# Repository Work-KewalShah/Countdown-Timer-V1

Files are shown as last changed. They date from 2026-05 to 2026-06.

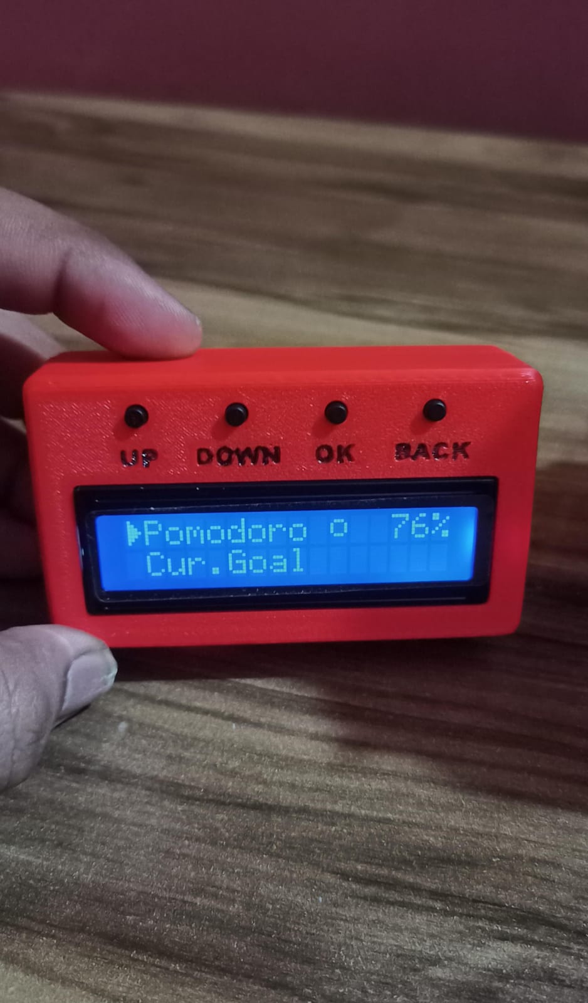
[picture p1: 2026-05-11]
images/Countdown_Timer_Build_Front.jpeg

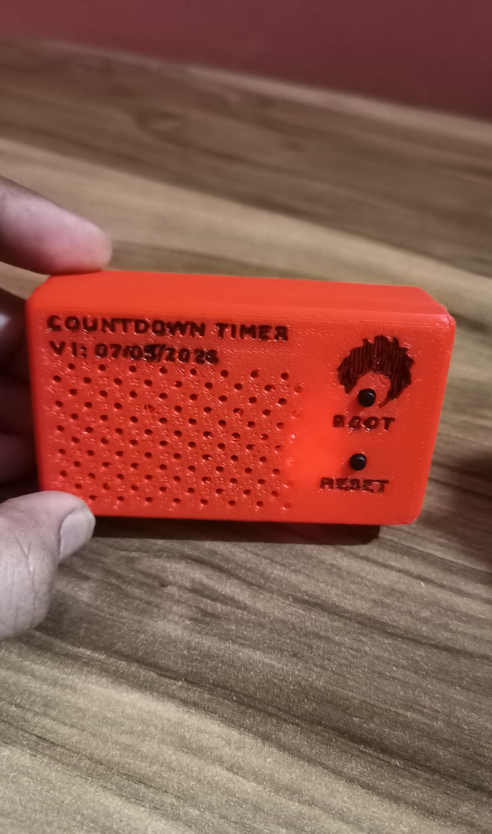
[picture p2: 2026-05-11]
images/Countdown_Timer_Build_Back.jpeg

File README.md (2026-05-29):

# Countdown Timer V1

<div align="center">
  Countdown Timer Hero Shot
</div>

<br/>

<div align="center">
  A battery-powered handheld countdown timer built on ESP32 with a 3D printed snap-fit case - track multiple goals simultaneously, run a stopwatch, save state across power cycles, and play a cute little game while you wait.
</div>

---

## Badges

<div align="center">







</div>

---

## Gallery

<div align="center">

| | |
|:---:|:---:|
| Countdown Timer - Build Front | Countdown Timer - Build Back |
| Build - Front | Build - Back |
| Countdown Timer - Front | Countdown Timer - Back |
| Render - Front | Render - Back |

</div>

---

## Table of Contents

- [What Is This](#what-is-this)
- [Features](#features)
- [Hardware](#hardware)
- [Wiring](#wiring)
- [How It Works - Software](#how-it-works---software)
- [Case Design](#case-design)
- [Programming the Device](#programming-the-device)
- [Skills Learned](#skills-learned)
- [Major Problems and Solutions](#major-problems-and-solutions)
- [V2 Planned Improvements](#v2-planned-improvements)
- [Repository Structure](#repository-structure)
- [License](#license)
- [Author](#author)

---

> This project exists because I needed to learn 3D Modelling and the only way I prefer learning something is by building something real with it, not by simply following tutorials.
>
> One week. Zero prior CAD experience. A functional snap-fit enclosure with port cutouts, engraved logos, ventilation geometry, toleranced joints, and a deadline I set for myself.
>
> The timer on the device was literally counting down to its own completion ;)

---

## What Is This

I generally build dedicated hardware devices for my own use - tools that solve specific problems in how I work and think. This is one of them.

I was deep into building a handheld Cyberdeck - most of the electronics and software were done, but the case design remained. I had never done 3D modelling before and needed to learn it properly with accurate dimensions, custom fits, and proper strain free joints. I needed a smaller, simpler project to learn on before tackling the Cyberdeck case with complex fixtures and fittings.

The project idea came one night when I was thinking about the Cyberdeck itself. I had set a deadline to finish it but the deadline kept slipping - I was only at 60% completion and had been for a while. The problem was not motivation, it was visibility. If I cannot physically see a deadline, I tend to procrastinate or keep adding scope without realising how much is already on my plate. That is true for the Cyberdeck (I kept adding features after features on top of an already stacked lineup) and for most of my tasks.

So the idea was simple - build a physical device that shows me exactly how much time is left for my current goal. Not a phone app. Not a widget on a screen I share with twenty other distractions. A dedicated physical object sitting on my desk with one job: show me the time I have left!

I also tend to prefer staying disconnected from my phone for most of my work - I use it for calls and messages, which is what phones were originally for. Separate dedicated devices for music, timers, and entertainment keep me focused. This device fits that philosophy.

As a side project it hit everything I needed - a real use case, materials I already had, a chance to learn 3D modelling and 3D printing before the Cyberdeck case, and something genuinely useful when done. It also turned into a much deeper learning experience than expected, covering embedded systems, battery management, NVS flash storage, CAD, slicing, and debugging across both hardware and software.

---

## Features

<div align="center">
  Main Menu Go Through
</div>

<br/>

### Countdown Timers
- **Three independent named slots** - Pomodoro, Current Goal, General - all running simultaneously in the background
- Set time in days, hours and minutes per slot
- Each slot has its own Start/Stop, Set Time, Full Screen and Reset options
- Finished slot triggers an alert regardless of which screen you are currently on

### Stopwatch
- Counts up from zero like a stopwatch
- Pause and resume with the OK button
- Runs in the background when you navigate away
- Takes display priority over countdowns when running

### Smart Backlight and Power Management
- **Dims automatically** after 1 minute of no interaction - always
- **Screen off** after 3 minutes if nothing is running, 4 minutes if only Current Goal is running
- **Stays dimmed indefinitely** if Pomodoro or General is running - glanceable without waking
- Any button press wakes to full brightness instantly
- WiFi and Bluetooth disabled on boot, CPU throttled to 80MHz - battery focused

### State Save and Resume
- Countdown state saved to NVS flash every 10 seconds while running
- On reboot, prompts to resume from last saved point
- Survives full power loss - picks up within ~10 seconds of where it left off

### Idle Behaviour
- **2 minutes idle** - switches to fullscreen countdown of the most urgent timer
- Stopwatch takes display priority over countdowns when running
- If nothing is running - snake animation across the display perimeter
- Backlight dim logic applies to all idle screens

### Battery Indicator
- Live battery percentage always visible in top right corner of every screen
- LiPo discharge curve lookup table for accurate mid-range readings
- 5-reading ADC average to reduce noise

### Dodge Duck Game
- Built-in dodge game accessible from the main menu
- Score is seconds survived
- Obstacle speed increases every 5 seconds
- OK to pause/resume, BACK to exit, score displayed bottom right

### Physical Controls and Ports
- 4 navigation buttons - UP, DOWN, OK, BACK - labelled on case
- BOOT and RESET accessible from back of case without opening
- USB-C charging port on right face, Micro USB upload port on left face
- Snap fit 3D printed case - no screws

---

## Hardware

| Component | Model | Purpose |
|---|---|---|
| Microcontroller | [ESP-WROOM-32](https://robu.in/product/esp-wroom-32-wifi-bluetooth-networking-smart-component-development-board) | Main processor, NVS storage, GPIO |
| Display | [LCD1602 Parallel - Blue Backlight](https://robu.in/product/basic-16x2-character-lcd-white-on-blue-on-blue-5v) | 16x2 character display |
| Charging Module | [TP4056 Type-C with Overcurrent Protection](https://robu.in/product/tp4056-1a-li-ion-lithium-battery-charging-module-with-current-protection-type-c) | LiPo battery charging and protection |
| Battery | [KP 403450 1000mAh LiPo](https://zbotic.in/product/kp-original-403450-1000mah-3-7vsingle-cell-rechargeable-lipo-battery/) | Power source |
| Buttons | [6x6x8mm Tactile switches x 6](https://robu.in/product/6x6x8mm-tactile-push-button-switch-pack-of-20) | 4 navigation + BOOT + RESET |
| Resistors | [10kΩ x 2](https://robu.in/product/mf25-10k-multicomp-pro-through-hole-resistor-10-kohm-250-mw-%c2%b1-1-axial-leaded-250-v), [470Ω x 1](https://robu.in/product/470-ohm-0-25w-metal-film-resistor-pack-of-100) | Voltage divider (battery sense) + backlight current limit |
| Wire | CAT5 cable strands 24 AWG | Internal point to point wiring |

<br/>

### Power Architecture

The TP4056 handles all charging via USB-C. Its OUT+ rail powers everything directly - ESP32 VIN, LCD VDD, and the top of the voltage divider. There is no separate 3.3V or 5V boost converter - the system runs at raw battery voltage (3.3V-4.2V) which the ESP32 and LCD both handle within spec.

```
Battery (+) ──► TP4056 B+
TP4056 OUT+ ──► ESP32 VIN
           ──► LCD Pin 2 (VDD)
           ──► Voltage Divider R1 top
TP4056 OUT- ──► Star Ground Junction
           ──► ESP32 GND
           ──► LCD Pin 1 (VSS)
           ──► All button GND legs
           ──► Voltage divider R2 bottom
```

### Voltage Divider - Battery Sense

Two 10kΩ resistors form a divider from OUT+ to GND. The midpoint connects to ESP32 GPIO 34 (input only, no pullup). At full charge (4.2V) the midpoint sits at 2.1V - safely within the ESP32's 3.3V ADC limit. LCD Pin 3 (V0/contrast) is tied directly to GND - no resistor needed, works correctly for this specific module at battery voltage range.

```
OUT+ ──── R1 (10kΩ) ──── junction ──── R2 (10kΩ) ──── GND
                              |
                          GPIO 34
```

---

## Wiring

<div align="center">
  Countdown Timer V1 - Wiring Diagram
</div>

<br/>

> For the full annotated diagram with pin tables, power connections, voltage divider breakdown and GND star junction detail - download the [PDF version](wiring/Countdown_Timer_V1_Wiring_Diagram.pdf)

<br/>

### Pin Mapping

| ESP32 Pin | Connects To | Purpose |
|---|---|---|
| VIN | TP4056 OUT+ | Main power input |
| GND | TP4056 OUT- | System ground |
| GPIO 2 | 470Ω - LCD Pin 15 (A) | Backlight PWM |
| GPIO 12 | LCD Pin 6 (E) | LCD Enable |
| GPIO 13 | LCD Pin 4 (RS) | LCD Register Select |
| GPIO 14 | LCD Pin 11 (D4) | LCD Data bit 4 |
| GPIO 25 | LCD Pin 14 (D7) | LCD Data bit 7 |
| GPIO 26 | LCD Pin 13 (D6) | LCD Data bit 6 |
| GPIO 27 | LCD Pin 12 (D5) | LCD Data bit 5 |
| GPIO 32 | Button DOWN | Navigation |
| GPIO 33 | Button UP | Navigation |
| GPIO 18 | Button OK | Navigation |
| GPIO 19 | Button BACK | Navigation |
| GPIO 34 | Voltage divider junction | Battery sense (input only) |
| EN | Button RESET | External reset |
| GPIO 0 (BOOT pad) | Button BOOT | External flash mode |

<br/>

### LCD Pin Reference

| LCD Pin | Label | Connects To |
|---|---|---|
| Pin 1 | VSS | GND |
| Pin 2 | VDD | TP4056 OUT+ |
| Pin 3 | V0 | GND (contrast fixed) |
| Pin 4 | RS | GPIO 13 |
| Pin 5 | RW | GND |
| Pin 6 | E | GPIO 12 |
| Pin 7-10 | D0-D3 | Not connected (4-bit mode) |
| Pin 11 | D4 | GPIO 14 |
| Pin 12 | D5 | GPIO 27 |
| Pin 13 | D6 | GPIO 26 |
| Pin 14 | D7 | GPIO 25 |
| Pin 15 | A (Anode) | 470Ω - GPIO 2 |
| Pin 16 | K (Cathode) | GND |

<br/>

### Component Layer Stack

<div align="center">
  Countdown Timer - Stack
</div>

<br/>

### Internal Wiring Notes
- All wiring is point to point using individual CAT5 cable strands - solid core 24 AWG
- All GND connections meet at a single star junction point - TP4056 OUT- and ESP32 GND together, everything else radiates from there
- BOOT button soldered directly to the onboard BOOT button pads on the ESP32 PCB since GPIO 0 is not broken out on the header of this board variant

---

## How It Works - Software

The firmware is a state machine built in Arduino C++ running on ESP32. Every screen in the UI is a defined state - the main loop reads the current state, handles button input, updates the display, and manages all background tasks simultaneously without blocking. All three countdown slots tick independently every loop iteration. The display only redraws when something actually changes - a second ticking, a button press, a slot finishing - keeping the LCD flicker free.

<br/>

### Countdown Timers

<div align="center">
  Countdown Time Set and Full Screen
</div>

<br/>

Each slot stores its target as an absolute `millis()` timestamp. Every loop iteration computes remaining seconds from that target. Only redraws when the second value changes - no flickering.

<br/>

### Stopwatch

<div align="center">
  Timer Demo
</div>

<br/>

The stopwatch tracks elapsed time by storing a `startMillis` timestamp and accumulated `elapsedSeconds` at each pause point. On resume it sets a new `startMillis` and adds to the accumulator - no drift, no dependency on absolute time.

<br/>

### Smart Backlight and Power Management

<div align="center">
  Auto Dim While Countdown
</div>

<br/>

Three backlight states managed by a runtime check every loop iteration. Behaviour depends on which slots are currently running - not a fixed timer.

| Condition | 1 Minute | 3 Minutes | 4 Minutes |
|---|---|---|---|
| Nothing running | DIM | OFF | - |
| Only Cur.Goal running | DIM | - | OFF |
| Pomodoro or General running | DIM | stays DIM forever | - |
| Stopwatch running | DIM | stays DIM forever | - |

WiFi and Bluetooth are disabled immediately on boot. CPU is throttled to 80MHz. Combined with smart backlight this gives approximately **20-28 hours** of battery life from the 1000mAh cell depending on usage pattern.

<br/>

### NVS State Save and Resume

<div align="center">
  Reset and Resume Countdown
</div>

<br/>

Each running countdown slot saves its remaining seconds to ESP32 NVS flash every 10 seconds. On reboot the firmware reads all three slots, checks for any that were running, and presents a resume prompt before the main loop starts ticking - preventing a race condition where the tick would mark slots as finished before the user could respond. The stopwatch does not save to NVS - a stopwatch resuming from an unknown elapsed time after power loss serves no practical purpose.

<br/>

### Idle Behaviour

<div align="center">

| | |
|:---:|:---:|
| Snake Animation | Auto Dim While Countdown |
| Snake animation - nothing running | Auto dim - countdown running |

</div>

<br/>

After 2 minutes of no interaction the device switches automatically to an idle screen. Priority order:

1. **Stopwatch running** - stopwatch fullscreen
2. **Countdown running** - fullscreen of the slot with least time remaining (most urgent)
3. **Nothing running** - snake animation around the display perimeter

The snake has a directional triangle head that rotates to face its direction of travel, a solid neck block, and small circle body dots.

<br/>

### Dodge Duck Game

<div align="center">
  Dodge Duck Gameplay
</div>

<br/>

Accessible from the main menu as the 5th item. A duck on the left dodges bullets coming from the right. UP and DOWN switch rows. Score is seconds survived. Speed increases every 5 seconds. A pattern system controls obstacle rows - maximum 3 consecutive same-row bullets before a forced row switch. OK pauses/resumes, BACK exits cleanly to the main menu. The game tick runs independently of button presses - bullets move on their own clock regardless of player input.

---

## Case Design

Designed in **Autodesk Fusion 360**. Snap fit construction - no screws, no inserts. The case splits into two halves that press together and hold by friction fit tabs. Everything inside sits in dedicated pockets sized to the exact component dimensions with 0.2-0.3mm clearance for print tolerance.

<br/>

### Assembly

<div align="center">

| | |
|:---:|:---:|
| Countdown Timer Exploded | Countdown Timer Component Assembly |
| Exploded view | Assembly sequence |
| Countdown Timer Front Buttons | Countdown Timer Back Cover Buttons |
| Front button assembly | Back cover button assembly |

</div>

<br/>

### Design Decisions

**Snap fit - no screws**
The two halves interlock via friction fit tabs along the inner perimeter. No screws means no inserts to install, no stripping risk, and faster assembly and disassembly. The wall thickness of 2.0mm gives enough rigidity that the tabs hold firmly without cracking under normal use.

**Screen placement**
The LCD sits in a dedicated bezel pocket on the front face. The cutout is sized to expose the full display area while the bezel hides the PCB edges cleanly.

**Button placement**
Four navigation buttons sit along the top edge of the front face with engraved labels below each - UP, DOWN, OK, BACK. Spacing is wide enough for comfortable thumb use without accidental adjacent presses.

**BOOT and RESET on back**
The two programming buttons are recessed on the back face with engraved labels. Separated from the navigation buttons so they cannot be pressed accidentally during normal use.

**Ventilation**
A dot matrix pattern covers most of the back face. Provides passive airflow around the Battery, TP4056 Charger and ESP32 - and acts as the primary aesthetic feature of the back alongside the engraved logo, version number and build date.

**Port cutouts**

<div align="center">

| | |
|:---:|:---:|
| Countdown Timer - USB C Cut | Countdown Timer - Micro USB Cut |
| USB-C - right face (charging) | Micro USB - left face (upload) |

</div>

Both ports accessible from outside the case without opening. USB-C on the right face for charging via TP4056. Micro USB on the left face for code upload to ESP32. Cutouts have 0.4mm clearance on each side for print tolerance.

**Logo engraving**
The character silhouette on the back is engraved at 0.4mm depth - exactly one nozzle width - which gives clean crisp edges at this scale. The logo is custom made and its SVG was imported into Fusion 360 directly from Inkscape and extruded as a cut.

<br/>

### Print Settings

Print settings can be changed depending on your filament and printer type.

| Setting | Value |
|---|---|
| Printer | Bambu A1 Mini |
| Material | PLA |
| Layer height | 0.2mm |
| Wall thickness | 2.0mm (5 perimeters at 0.4mm nozzle) |
| Wall loop | 3 |
| Infill | 20% Rectilinear |
| Nozzle | 0.4mm |
| Engraving depth | 0.4mm |
| Order of Walls | Outer/Inner |
| Print speed | 25mm/s Initial Layer, 50mm/s Initial Layer Infill |
|  | 60-70mm/s Outer Walls, 150mm/s Inner Walls |
| Min - Max Fan Speed | 40 - 40 |

<br/>

### Case Dimensions

| Dimension | Value |
|---|---|
| Width | ~86mm |
| Height | ~28.5mm |
| Depth | ~50mm |

---

## Programming the Device

### Requirements

| Tool | Details |
|---|---|
| Arduino IDE | 2.x or later |
| ESP32 Board Package | Version 3.x - install via Boards Manager, search ESP32 by Espressif |
| LiquidCrystal Library | By Arduino - install via Library Manager |
| Preferences | Built into ESP32 board package - no install needed |
| WiFi.h | Built into ESP32 board package - no install needed |

<br/>

### Board Settings in Arduino IDE

| Setting | Value |
|---|---|
| Board | ESP32 Dev Module |
| Upload Speed | 115200 |
| CPU Frequency | 240MHz (set in code to 80MHz at runtime) |
| Flash Size | 4MB |
| Partition Scheme | Default |
| Port | whichever COM port your ESP32 appears on |
| Firmware | CP210x_Windows_Drivers (for my specific board, yours can be different) |

<br/>

### Upload Procedure

Since the ESP32 and BOOT button are inside the case, use the external BOOT and RESET buttons on the back face.

<div align="center">
  Boot Button Demo
</div>

<br/>

1. Connect Micro USB cable to the left face port
2. Open Arduino IDE and select the correct COM port
3. Hold the **BOOT** button on the back of the case
4. While holding BOOT, press and release the **RESET** button
5. Release BOOT
6. Click **Upload** in Arduino IDE
7. Wait for upload to complete
8. Press **RESET** once to restart the device and run the new firmware

> If upload fails with an MD5 mismatch error, try a different USB cable - power-only cables have no data lines and look identical to data cables. Also try enabling Clear Flash while uploading new firmware in Tools and lowering upload speed to 115200 in Tools - Upload Speed.

<br/>

### First Flash - NVS

On the very first upload to a fresh ESP32, NVS is empty and the device boots straight to the main menu. No action needed. If you are reflashing over an existing build and want to clear saved timer state, add this temporarily to the top of `setup()` and upload once, then remove and upload again:

```cpp
prefs.begin("slot0", false); prefs.clear(); prefs.end();
prefs.begin("slot1", false); prefs.clear(); prefs.end();
prefs.begin("slot2", false); prefs.clear(); prefs.end();
```

<br/>

### Navigation Reference

| Button | General Use | In Game | In Set Time |
|---|---|---|---|
| **UP** | Scroll up / increment | Move duck to top row | +1 (hold for auto repeat) |
| **DOWN** | Scroll down / decrement | Move duck to bottom row | -1 (hold for auto repeat) |
| **OK** | Confirm / enter / start | Pause / resume / retry | Confirm and next field |
| **BACK** | Go back one level | Exit to main menu | Previous field / exit |

---

## Skills Learned

This project covered a much broader range of skills than expected - embedded C++, ESP32 architecture, battery management, parallel LCD communication, CAD, 3D printing, slicing, and systematic hardware debugging.

The full breakdown with specifics on each skill, what was learned from zero, and what surprised me most is in the [build journey document](My_Journey.md).

---

## Major Problems and Solutions

Five significant bugs and hardware issues were encountered and resolved during this build - GPIO silent pullup failure, battery ADC double correction, NVS type mismatch producing garbage resume values, a boot sequence race condition marking timers as finished before the resume prompt appeared, and an infinite blocking loop freezing the device on button press.

Full root cause analysis, fixes and lessons for each in [My_Journey.md](My_Journey.md).

---

## V2 Planned Improvements

V1 is complete and functional. These are the improvements planned for the next revision.

<br/>

### Hardware Changes

**Passive Buzzer - Audio Alerts**
A passive buzzer on any free GPIO pin for countdown completion alerts. Currently the only alert is a screen notification which is easy to miss if the device is face down or in a bag.

**Screen Tilt - Better Desk Viewing Angle**
Tilting the screen pocket back 10-15 degrees in Fusion 360 for better readability when the device sits on a desk without picking it up.

**Power Toggle Switch**
A slide or toggle switch inline on the battery positive wire for clean power off without disconnecting the battery physically.

<br/>

### Software Changes

**DS3231 RTC Module - Accurate Power-Off Time Tracking**
Currently the device treats power-off as a pause and resumes from the last saved point. A DS3231 RTC module connected via I2C would calculate exact elapsed time during power-off and subtract it from remaining seconds on resume - making the countdown accurate across reboots.

---

## Repository Structure

```
Countdown-Timer-V1/
│
├── firmware/
│   └── Countdown_Timer_V1.ino
│
├── case/
│   └── Countdown_Timer_V1_Case.3mf
│
├── wiring/
│   ├── Countdown_Timer_V1_Wiring_Diagram.png
│   └── Countdown_Timer_V1_Wiring_Diagram.pdf
│
├── images/
│   ├── Countdown_Timer_Build_Front.jpeg
│   ├── Countdown_Timer_Build_Back.jpeg
│   ├── Countdown_Timer_Front.png
│   ├── Countdown_Timer_Back.png
│   ├── Countdown_Timer_Stack.png
│   ├── Countdown_Timer_USB_C_Cut.png
│   └── Countdown_Timer_Micro_USB_Cut.png
│
├── My_Journey.md
├── LICENSE
└── README.md
```

<br/>

### File Notes

**firmware/Countdown_Timer_V1.ino** - Single file sketch, no external dependencies beyond the ESP32 board package and LiquidCrystal library.

**case/Countdown_Timer_V1_Case.3mf** - Both case halves and all internal fittings. Supports needed only for the front outer piece. Keep flat faces on the plate and clean the bed with IPA before printing.

**wiring/Countdown_Timer_V1_Wiring_Diagram.pdf** - Full annotated reference with pin tables and connection detail. Use this over the PNG for proper zoom.

---

## License

This project is open source under the [MIT License](LICENSE).

You are free to use, modify, and distribute this project for personal or commercial purposes. Attribution appreciated but not required.

---

## Author

**Kewal Shah**

B.E. in Information Technology, self-taught builder, and someone who finds it genuinely difficult to stop once something is interesting enough.

I work across embedded systems, software, cybersecurity, and hardware design - not because I planned a neat career path across all of them, but because each problem I solve tends to open three more that I cannot leave alone. Cybersecurity is where I am currently going deep - drawn to it for the same reason I am drawn to hardware: there is always something underneath the surface that most people do not look at.

This project is a good example of how I learn. I needed to know Fusion 360 for the Cyberdeck case. Rather than doing tutorials, I built something real, from scratch, under self-imposed pressure, in about a week - and ended up with a fully functional snap-fit enclosure with port cutouts, engraved logos, ventilation geometry, and print tolerancing that actually works. That is the only way learning sticks for me.

V1 completed 07/05/2026 - technically in the early hours of 8th May around 3am, but I was not going to redesign the case and reprint just to change a date, so 7th May it is :)

V2 after Cyberdeck completion. [Read the full build journey](My_Journey.md).

<br/>

| | |
|---|---|
| GitHub | [@Work-KewalShah](https://github.com/Work-KewalShah) |
| LinkedIn | [Kewal Shah](https://www.linkedin.com/in/kewal-shah-work/) |

<br/>

> *"If I can't physically see the deadline, I tend to procrastinate - so I built something that makes it impossible to ignore."*

---

<div align="center">

**If this project helped you or inspired a build of your own, consider leaving a ⭐ on the repository.**

</div>

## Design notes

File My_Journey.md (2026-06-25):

# The Journey - Countdown Timer V1

*This is not the technical documentation. The README covers that.*
*This is everything else.*

---

## The Night It Started

It was sometime in the middle of April. I was in bed, phone in hand, scrolling through YouTube looking for something interesting to watch. Nothing was landing. And somewhere between two videos I would not remember the next morning, a thought cut through the noise.

*How much more of my time is the Cyberdeck going to take?*

The Cyberdeck had been my main project for a while. Most of the electronics were done. The software was done. What remained was the controls, the buttons, and the case - the physical shell that would hold everything together. I had been putting it off because I had zero knowledge of CAD. I had never modelled anything in 3D. I had never designed a case, never thought about tolerances, never opened Fusion 360 for more than five minutes.

And then the second thought arrived, right behind the first.

*I don't have a real deadline for any of this.*

That was the honest truth. I had set dates for myself before. I had missed most of them. Not because I was not capable, but because a deadline you cannot see is a deadline you can negotiate with yourself. I was good at that negotiation. Too good.

I put the phone down and stared at the ceiling for a while.

*What if I built something that made the deadline impossible to ignore. A physical device. On my desk. Counting down. Always visible.*

And then the third thought, the practical one.

*I need to learn CAD anyway for the Cyberdeck case. This could be the project I learn it on.*

By the time I fell asleep, the idea was already real enough to start the next morning.

---

## What I Knew. What I Didn't.

I should be honest about where I was starting from.

I had worked with a Raspberry Pi before through the Cyberdeck project. I knew soldering. I knew how to read a wiring diagram. I had some sense of how power rails work and how to not fry something expensive.

What I did not know: ESP32. Arduino IDE. Flashing firmware. LCD displays. CAD. 3D printing. Slicing software. Print settings. Tolerances. Friction fitting. Any of it.

There is something worth mentioning here. In my first semester of college, Electronics was my worst subject. I almost failed it. The theory felt disconnected from anything real. I could not hold onto it because I could not see why it mattered.

What changed was not a class or a teacher or a textbook. It was the drive to make something. To see an idea become a physical object that worked. Once that drive existed, electronics stopped being a subject I was bad at and became a tool I needed to learn. I did not even notice it getting easier because I was too focused on what I was trying to build.

That pattern has repeated itself every time since.

---

## 7.5 Days

I gave myself until the 7th of May.

The build took 7.5 days. I finished at 3am on the 8th. I was not going to redesign the case and reprint everything just to change a date, so the 7th of May it is.

There was one day in the middle where I did not build anything. The prints kept warping. They were not sticking to the hotbed. Every iteration was failing and I had not slept properly in two days. I hit a wall - not a technical wall, a human one. So I stopped.

The second season of Sapne vs Everyone had just come out. It is one of my favourite series. I watched it, slept, and came back the next day.

Sometimes the most productive thing you can do is stop.

---

## Learning CAD - The Door Handle

Before I could touch the Countdown Timer case, I needed to actually learn Fusion 360. Not from tutorials - from a real problem.

The kitchen closet door handle had broken. I decided to model and print a replacement. Simple enough to be achievable in a day or two, complex enough to actually teach me something. Curves, extrudes, fillets, real-world dimensions - everything I would need for the case.

I did not have a digital caliper. I measured the original handle with a manual Vernier caliper and drew up the dimensions in Canva - because I know Canva well and it was the fastest way to get a clean dimensional reference I could work from.

<div align="center">

| | |
|:---:|:---:|
| Original Door Handle | Canva Screen Door Handel Dimensions |
| Reference handle | Dimensions mapped in Canva |

</div>

Then I opened Fusion 360 and started modelling. Getting the curves right, understanding how constraints work, building it so that changing one dimension does not collapse the whole sketch - none of it came easily at first. But the door handle was a concrete thing I could hold and measure and compare against. That made the learning stick in a way that a tutorial exercise never would have.

<div align="center">
  Fusion Screen Door Handle Final
  <br/>
  <em>Final door handle model in Fusion 360 - timeline and browser visible</em>
</div>

<br/>

Then printed it.

<div align="center">

| | |
|:---:|:---:|
| 3D Printing Door Handle | 3D Printer Printing Door Handle Gif |
| Printing the handle | Print in progress |

</div>

<div align="center">

| | |
|:---:|:---:|
| 3D Printed Door Handle in Hand | 3D Printed Door Handle Fitted |
| Final Printed handle | Fitted in the closet |

</div>

It fit. It worked. The closet door opens and closes on a handle I designed and printed myself.

More importantly - I now knew enough Fusion 360 to start the case.

---

## The Build - Hardware

The hardware side of this build was the part I was most comfortable with coming in, and even then it surprised me.

I started the way I always start - wiring diagram first. Understanding how power flows, how communication works, what connects to what and why. Then temporary wiring on a breadboard to test everything before committing to anything permanent.

The ESP32 was new territory. I had never touched Arduino IDE, never flashed a microcontroller this way, never written code for a device with no operating system underneath it. Everything had to be thought about differently - no threads, no background processes, just a single loop running over and over, handling everything simultaneously without blocking.

The wiring itself came together using CAT5 cable strands - solid core, thin, exactly right for point to point work inside a small case. All ground connections meeting at a single star junction. Power flowing from the TP4056 directly to everything. Simple and clean.

At some point during the build I had the main component stack assembled and seated - ESP32, TP4056, LCD, battery all stacked and wired before the case was finalised. This is what the inside looked like before it was closed up.

<div align="center">

| | |
|:---:|:---:|
| Middle Component Stack Main | Middle Component Stack Port View 1 |
| Component stack - main view | Port side view 1 |
| Middle Component Stack Port View 2 | |
| Port side view 2 | |

</div>

<div align="center">

| | |
|:---:|:---:|
| Middle Component Stack Gif 1 | Middle Component Stack Gif 2 |
| Component stack - with battery plate | Component stack - witout battery plate |

</div>

Claude helped significantly with the firmware. The state machine architecture, the NVS save and resume logic, the backlight management, the game. I would describe what I wanted, we would work through it together, and I would push back when something was wrong - which happened more than once. The custom LCD characters, some of the menu navigation logic, certain game behaviours - those needed correction and iteration the same way the hardware did. The collaboration worked because I knew what I wanted the device to do, even when I did not know exactly how to make it do that.

Without that collaboration I am certain I would have spent significantly longer on the firmware. I am also certain I would have wired something backwards and damaged the ESP32 at least once.

---

## The Build - Case

This is where the real learning happened.

The door handle had given me the basics. Now the case was a different challenge - internal pockets, port cutouts, button holes, snap fit joints, tolerancing everything for real-world print dimensions. Much more complex. Much more at stake because everything needed to fit together at the end.

<div align="center">
  Fusion Screen Countdown Timer Final
  <br/>
  <em>Final Countdown Timer V1 case in Fusion 360</em>
</div>

<br/>

The case design went through more iterations than I initially expected. Every print revealed something that needed changing. The LCD cutout was too tight. The port openings were slightly off. The button holes needed more clearance. The support columns inside were the wrong height. Each iteration meant printing, fitting, identifying the problem, going back to Fusion, changing the dimension, printing again.

I have two boxes. They are sitting on my desk. They are full of every failed and partial print from this build - every wrong version of every part. Every piece of PLA that taught me something. Those boxes are probably the most honest representation of what this build actually looked like from the inside.

<div align="center">
  Prototype Prints Filled Box
  <br/>
  <em>Every failed print. Every lesson.</em>
</div>

<br/>

One of those iterations taught me something I did not expect. I had designed circular columns inside the case to hold the LCD and the LCD backplate in position. On one fitting attempt, one of the columns broke. I looked at it for a moment and thought - what if I just remove it entirely? The LCD was fitting tightly enough without it. The column was gone in the next version and the fit was actually cleaner. Sometimes the constraint you designed around is not necessary.

The print failures were their own education. Warping. Stringing. Layers not adhering. Prints lifting off the hotbed halfway through a two hour job. After not sleeping for two days, watching a print fail an hour in is a specific kind of frustration. I learned the slicing settings, the temperatures, the bed adhesion techniques, the support placement, when to use brims and when not to. None of this was in the plan when I started. All of it is now knowledge I will use on the Cyberdeck case.

The snap fit joints worked for this build. For the Cyberdeck I will use heat inserts and screws - snap fit loosens over time no matter how well it is designed. That is one of the things this build taught me that directly changes how I approach the next one.

One of the last things I did before calling it done was colour the engraved text and logo on the back with a black marker. The PLA was red. The engravings were shallow. The marker filled them and made everything readable. A simple thing that made a real difference to how the finished device looked.

---

## The Hardest Parts

**The case, overall.** Not any single element of it - the cumulative weight of iteration after iteration, print after print, dimension after dimension. Getting accurate sizes for the LCD cutout, the USB-C port, the Micro USB port, the button holes - all of it required understanding how print settings affect actual printed dimensions. A hole that is 28mm in CAD does not print as 28mm. Learning that gap between design and reality was the steepest part of the learning curve.

**The NVS resume bug.** On the software side this was the most stubborn problem. The device would save state correctly. On reboot it would show the DONE alert before the resume prompt even appeared. Then when we fixed that, the resumed time was completely wrong - 49 days instead of 57 minutes. The root cause was a type mismatch between NVS key types across different versions of the firmware. Tracking it down through Serial Monitor output, one hypothesis at a time, was a proper debugging exercise. It took multiple sessions.

**The button freezing.** Occasionally pressing a button would freeze the entire device. No display update, no response, nothing. Required a full battery disconnect to recover. The cause was an infinite blocking loop in the button release detection - a while loop with no timeout that would hang forever if a button contact stuck even slightly. The fix was simple once found. Finding it was not.

---

## The Unexpected Things

CAD was harder than I expected. I had assumed that with some geometry knowledge and some patience I would pick it up quickly. The geometry helped. The patience was tested.

The broken column that improved the design. I did not plan to remove it. The print forced the decision and the decision turned out to be right.

Coloring the engravings with a marker. That was not in any plan. It was a last minute idea at the end of a very long build. It was the right call and it is one of the details I am most happy with on the finished device.

How much the print settings matter. I knew in theory that slicing configuration affected output quality. I did not appreciate how much until I was debugging warping and adhesion failures at 1am.

---

## 3am. Done.

I was half asleep. I had not slept properly in days. The last print had come out right. The case had snapped together. The firmware was flashed. I picked up the device and powered it on.

The screen lit up. The main menu appeared. I navigated to Current Goal and started the countdown. It ran.

I held it in my hands for a moment.

The last time I felt that specific kind of pride was three or four years earlier. My team had placed second in the nation at the NSG Digirakshak Hackathon. I was the team leader. That was a different kind of achievement - collaborative, competitive, external validation.

This was different. This was just me, a box of failed prints, a reel of CAT5 wire, and something that existed now that did not exist a week ago.

Something of my own. A single piece in the world. Nothing else exists like it anywhere. Not in any store, not on any shelf, not in anyone else's hands. Just mine.

These photos were taken at 2:38am on 8th May 2026. The soldering table still visible in the background. The timestamp is in the image.

<div align="center">

| | |
|:---:|:---:|
| Final Countdown Build Front | Final Countdown Build Back |
| Front - 2:38am, 08/05/2026 | Back - 2:38am, 08/05/2026 |
| Final Countdown Build Port Cutout USB C | Final Countdown Build Port Cutout Micro USB |
| USB-C port cutout | Micro USB port cutout |

</div>

I went to sleep.

---

## What It Changed

I use it every day now.

When I sit down to work I set a countdown for whatever I am trying to finish. When I study I run the Pomodoro timer. When I play games I start the stopwatch so I can see honestly how much time I am spending.

The awareness is the thing. Not the pressure - I am not watching the countdown anxiously. It is more that the device sitting on my desk makes time visible in a way that a phone app never did. The phone lives in my pocket, behind a lock screen, surrounded by everything else competing for my attention. The device has one job. It does it without asking for anything back.

I procrastinate less. Not because the countdown terrifies me, but because I can see the time passing and I cannot pretend I cannot.

---

## Where This Fits

When I was in school I was editing videos, making graphics, learning animation. I thought those were hobbies. I used all of them making the advertisement video for this build.

When I was in class eleven and twelve I was learning geometry. I thought it was abstract and theoretical. I used it in Fusion 360 sketches.

When I almost failed Electronics in my first semester I thought that subject and I were permanently incompatible. I have now built a working embedded device and am halfway through a Cyberdeck build that involves managing power, RF shielding, and complex wiring in a constrained space.

Nothing you learn is wasted. The only thing that changes is when it becomes useful.

This project is a step in a longer journey. Next is the Network+ exam. Then completing the Cyberdeck - which now has a working case designer behind it. Then Security+. Both this device and the Cyberdeck will be fully open source. I want to keep building things that are useful - to me first, and then to anyone else who wants them.

The maker's journey does not have a destination. It just has the next build.

---

## To Anyone Who Wants to Build Something

Start anyway.

You will not know everything you need to know before you begin. You are not supposed to. The knowing comes from the doing, and only from the doing.

You will hit walls. Some of them are technical. Some of them are just exhaustion and frustration wearing the costume of a technical problem. Learn to tell the difference. When it is the second kind - stop, rest, come back. The problem will still be there. So will you.

Use every tool available to you. AI, documentation, communities, people who have done it before. Using help is not a shortcut. It is how every builder who has ever built anything has worked. None of them did it entirely alone.

And when it is done - when you are holding it in your hands at 3am and it is working and it is real - that feeling belongs to you completely.

No one can build what you would build. That is the whole point.

---

*Kewal Shah* <br>
*V1 - 07/05/2026* <br>
*Cyberdeck - on the way*

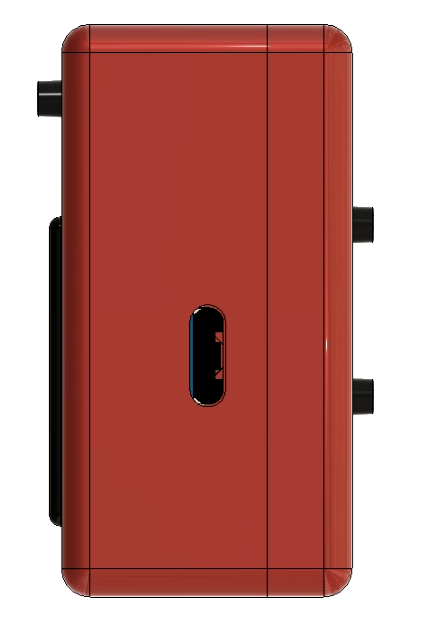
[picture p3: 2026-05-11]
images/Countdown_Timer_USB_C_Cut.png

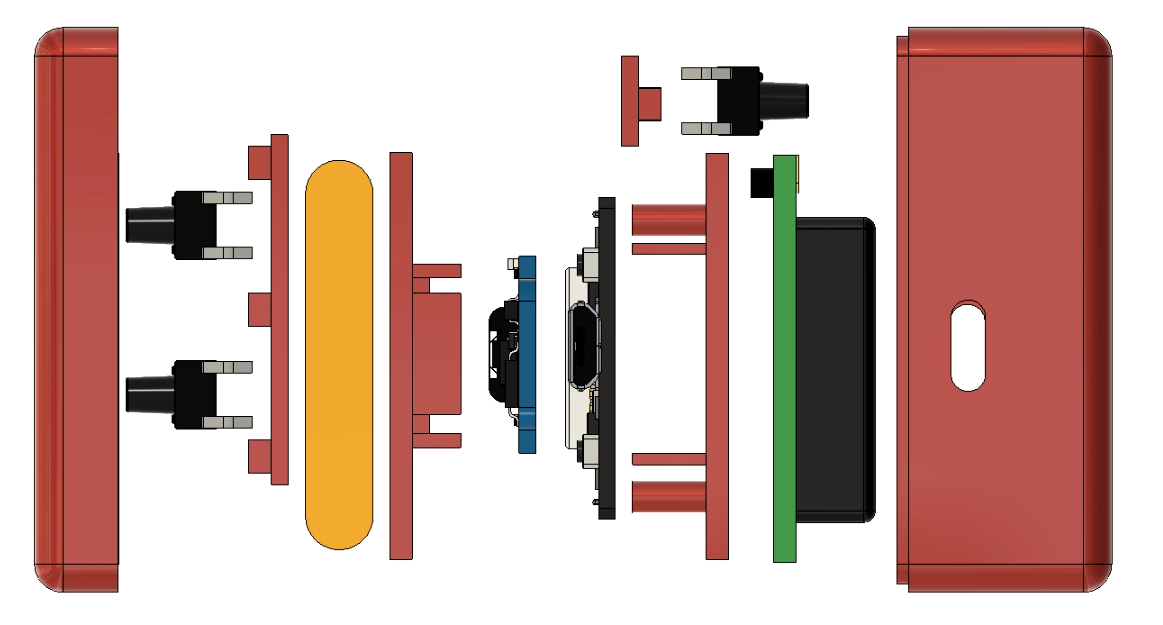
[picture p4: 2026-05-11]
images/Countdown_Timer_Stack.png

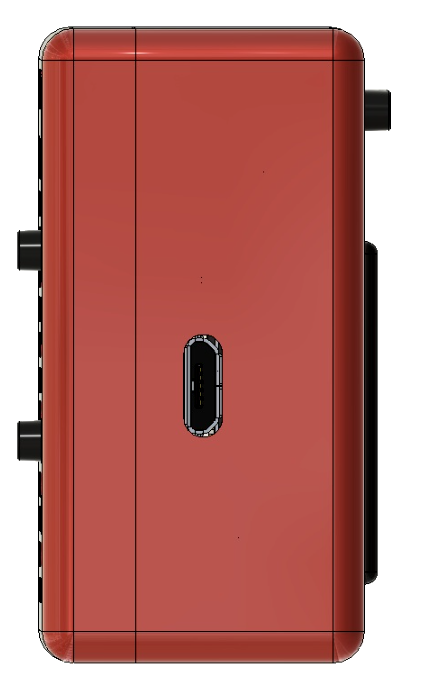
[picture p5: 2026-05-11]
images/Countdown_Timer_Micro_USB_Cut.png

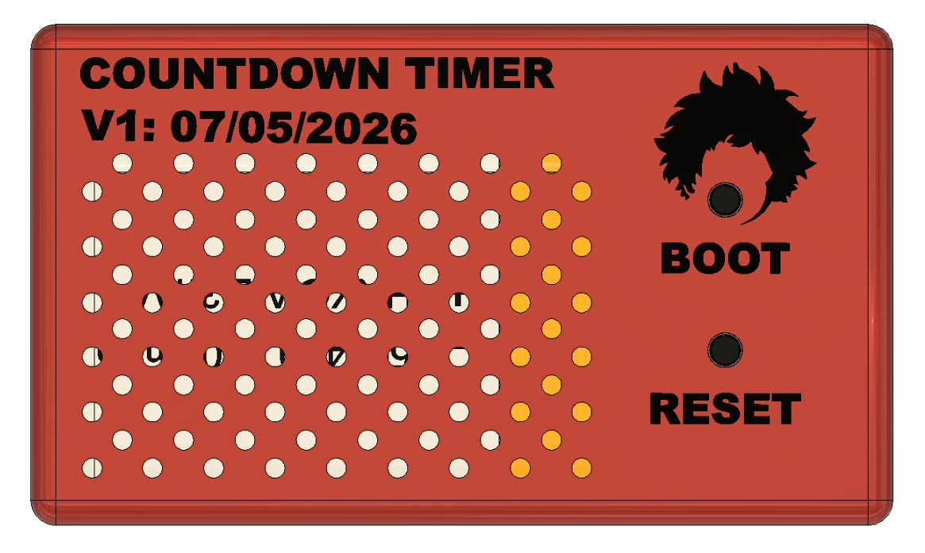
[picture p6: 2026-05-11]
images/Countdown_Timer_Back.png

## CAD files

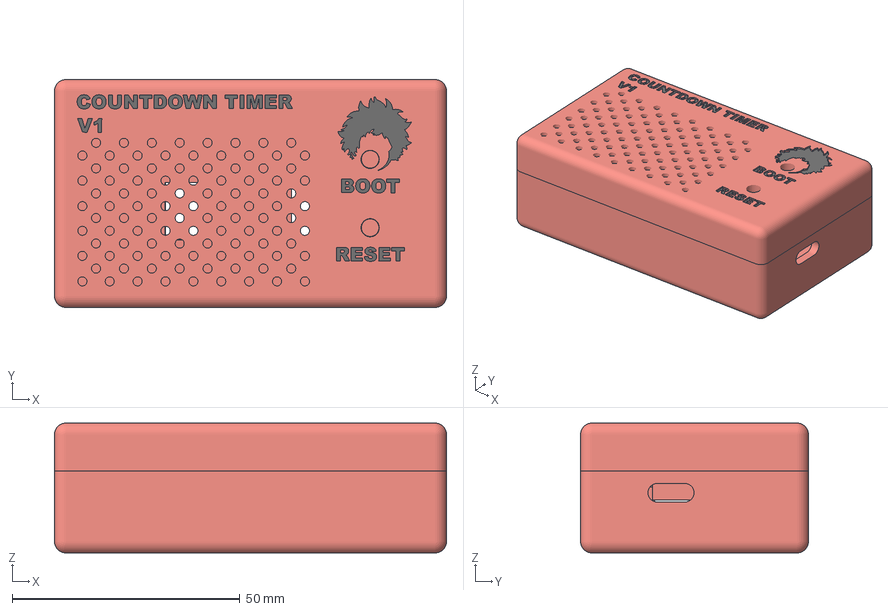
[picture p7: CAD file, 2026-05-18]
case/Countdown Timer V1 - Case.3mf
86.0 x 50.0 x 28.5 mm
Battery Backplate
Bottom 2 Rail
Bottom 4 Rail
Bottom
LCD Backplate
Top

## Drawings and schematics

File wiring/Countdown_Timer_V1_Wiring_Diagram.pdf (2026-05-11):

# Countdown Timer - V1

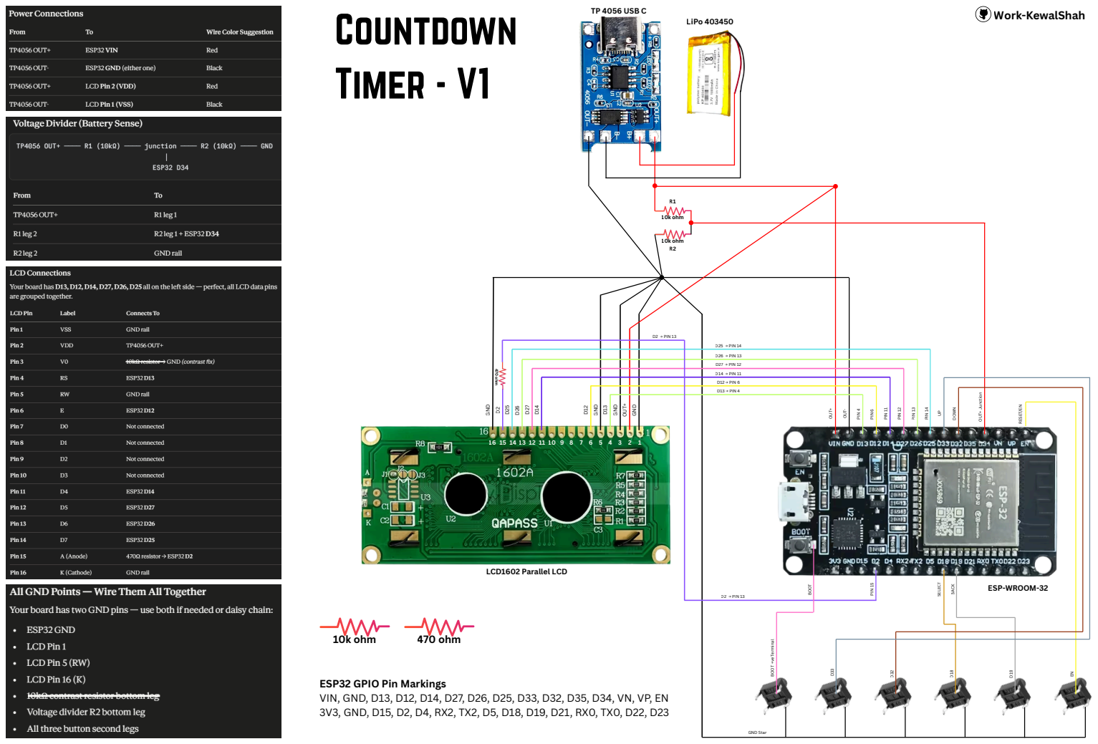
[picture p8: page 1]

D26 → PIN 13
D27 → PIN 12
D14 → PIN 11
D12 → PIN 6
D13 → PIN 4

ESP32 GPIO Pin Markings
VIN, GND, D13, D12, D14, D27, D26, D25, D33, D32, D35, D34, VN, VP, EN
3V3, GND, D15, D2, D4, RX2, TX2, D5, D18, D19, D21, RX0, TX0, D22, D23

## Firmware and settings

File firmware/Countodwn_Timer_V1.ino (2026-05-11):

#include <LiquidCrystal.h>
#include <Preferences.h>
#include <WiFi.h>

// ── Pins ──────────────────────────────────────────────────────────────────────
LiquidCrystal lcd(13, 12, 14, 27, 26, 25);

const int BTN_UP     = 33;
const int BTN_DOWN   = 32;
const int BTN_SELECT = 18;
const int BTN_BACK   = 19;
const int BACKLIGHT  = 2;
const int BATT_PIN   = 34;

// ── Backlight levels ──────────────────────────────────────────────────────────
const int BL_BRIGHT = 200;
const int BL_DIM    = 30;
const int BL_OFF    = 0;

// ── Timeout constants (ms) ────────────────────────────────────────────────────
const unsigned long T_DIM          =  60000UL;
const unsigned long T_OFF_NOTHING  = 180000UL;
const unsigned long T_OFF_CURGOAL  = 240000UL;
const unsigned long AUTOFS_TIMEOUT = 120000UL;
const unsigned long SAVE_INTERVAL  =  10000UL;

// ── Slot indices ──────────────────────────────────────────────────────────────
const int SLOT_POMODORO = 0;
const int SLOT_CURGOAL  = 1;
const int SLOT_GENERAL  = 2;

// ── Custom characters ─────────────────────────────────────────────────────────
byte charFilled[8]    = { 0b00000,0b01110,0b11111,0b11111,0b11111,0b01110,0b00000,0b00000 };
byte charHollow[8]    = { 0b00000,0b01110,0b10001,0b10001,0b10001,0b01110,0b00000,0b00000 };
byte charArrow[8]     = { 0b01000,0b01100,0b01110,0b01111,0b01110,0b01100,0b01000,0b00000 };
byte charSnakeNeck[8] = { 0b00000,0b11111,0b11111,0b11111,0b11111,0b11111,0b00000,0b00000 };
byte charSnakeBody[8] = { 0b00000,0b00000,0b00100,0b01110,0b01110,0b00100,0b00000,0b00000 };
byte charDuck[8]      = { 0b00110,0b00111,0b01110,0b11111,0b01110,0b01010,0b01010,0b00000 };
byte charBullet[8]    = { 0b00000,0b00100,0b01111,0b11111,0b01111,0b00100,0b00000,0b00000 };

byte charHeadR[8] = { 0b10000,0b11000,0b11100,0b11110,0b11100,0b11000,0b10000,0b00000 };
byte charHeadL[8] = { 0b00001,0b00011,0b00111,0b01111,0b00111,0b00011,0b00001,0b00000 };
byte charHeadD[8] = { 0b11111,0b11111,0b01110,0b01110,0b00100,0b00100,0b00000,0b00000 };
byte charHeadU[8] = { 0b00000,0b00100,0b00100,0b01110,0b01110,0b11111,0b11111,0b00000 };

// ── Countdown Slots ───────────────────────────────────────────────────────────
const int   NUM_SLOTS             = 3;
const char* SLOT_NAMES[NUM_SLOTS] = { "Pomodoro", "Cur.Goal", "General " };
const char* NVS_NS[NUM_SLOTS]     = { "slot0",    "slot1",    "slot2"    };

enum SlotState { SLOT_IDLE, SLOT_RUNNING, SLOT_FINISHED };

struct Slot {
  SlotState     state;
  long          setDays, setHours, setMins;
  unsigned long remainingSeconds;
  unsigned long targetMillis;
};
Slot slots[NUM_SLOTS];

// ── Stopwatch Timer ───────────────────────────────────────────────────────────
struct StopwatchState {
  bool          running;
  bool          paused;
  unsigned long elapsedSeconds;   // total elapsed at last pause
  unsigned long startMillis;      // millis() when last started/resumed
};
StopwatchState sw = { false, false, 0, 0 };

unsigned long swCurrentSeconds() {
  if (!sw.running) return sw.elapsedSeconds;
  return sw.elapsedSeconds + (millis() - sw.startMillis) / 1000UL;
}

void swStart() {
  sw.elapsedSeconds = 0;
  sw.startMillis    = millis();
  sw.running        = true;
  sw.paused         = false;
}

void swPause() {
  if (sw.running && !sw.paused) {
    sw.elapsedSeconds = swCurrentSeconds();
    sw.paused         = true;
    sw.running        = false;
  }
}

void swResume() {
  if (sw.paused) {
    sw.startMillis = millis();
    sw.running     = true;
    sw.paused      = false;
  }
}

void swStop() {
  sw.running        = false;
  sw.paused         = false;
  sw.elapsedSeconds = 0;
  sw.startMillis    = 0;
}

// ── Screens ───────────────────────────────────────────────────────────────────
enum Screen {
  SCR_MAIN,
  SCR_SLOT_MENU,
  SCR_SET_DAYS, SCR_SET_HOURS, SCR_SET_MINS,
  SCR_FULLSCREEN,
  SCR_CONFIRM_RESUME,
  SCR_GAME,
  SCR_IDLE_SNAKE,
  SCR_IDLE_FULLSCREEN,
  SCR_TIMER_MENU,
  SCR_TIMER_FULLSCREEN
};
Screen currentScreen    = SCR_MAIN;
Screen screenBeforeIdle = SCR_MAIN;

int selectedSlot   = 0;
int menuCursor     = 0;   // 0-4 (4 = Dodge Duck)
int slotMenuCursor = 0;
int timerMenuCursor = 0;  // 0=Full Screen  1=Stop & Reset

long tmpDays = 0, tmpHours = 0, tmpMins = 0;

// ── Timing ────────────────────────────────────────────────────────────────────
unsigned long lastActivity = 0;
unsigned long lastSaveTime = 0;

// ── Backlight state ───────────────────────────────────────────────────────────
enum BlState { BL_STATE_BRIGHT, BL_STATE_DIM, BL_STATE_OFF };
BlState blState = BL_STATE_BRIGHT;

// ── Alert ─────────────────────────────────────────────────────────────────────
int           alertSlot    = -1;
unsigned long alertShownAt = 0;
bool          showingAlert = false;

// ── Debounce ──────────────────────────────────────────────────────────────────
unsigned long lastBtnTime    = 0;
const unsigned long DEBOUNCE = 200UL;

// ── Snake animation ───────────────────────────────────────────────────────────
unsigned long lastSnakeTick = 0;
int           snakePos      = 0;
int           lastSnakeDir  = -1;
const unsigned long SNAKE_TICK = 120UL;

// ── Dodge Duck game ───────────────────────────────────────────────────────────
const unsigned long DODGE_TICK_START     = 300UL;
const unsigned long DODGE_TICK_MIN       =  70UL;
const unsigned long DODGE_SPEED_INTERVAL = 5000UL;

struct DodgeState {
  int           playerRow;
  int           obs1Col, obs1Row;
  int           obs2Col, obs2Row;
  unsigned long lastSecondTick;
  int           displayScore;
  bool          dead;
  bool          started;
  bool          paused;
  unsigned long tickMs;
  unsigned long lastSpeedUp;
  int           obsPattern;
  int           obsPatternCount;
  int           sameRowCount;
} dg;

unsigned long lastDodgeTick = 0;

Preferences prefs;

// ─────────────────────────────────────────────────────────────────────────────
// BATTERY
// ─────────────────────────────────────────────────────────────────────────────
const float battVoltTable[] = { 4.10, 3.95, 3.80, 3.70, 3.60, 3.50, 3.40, 3.30 };
const int   battPctTable[]  = {  100,   85,   70,   55,   40,   25,   10,    0  };
const int   battTableLen    = 8;

int getBattery() {
  long sum = 0;
  for (int i = 0; i < 5; i++) { sum += analogReadMilliVolts(BATT_PIN); delay(2); }
  float mv    = sum / 5.0f;
  float battV = (mv / 1000.0f) * 2.0f;
  if (battV >= battVoltTable[0])                return 100;
  if (battV <= battVoltTable[battTableLen - 1]) return 0;
  for (int i = 0; i < battTableLen - 1; i++) {
    if (battV <= battVoltTable[i] && battV >= battVoltTable[i + 1]) {
      float range = battVoltTable[i]     - battVoltTable[i + 1];
      float pos   = battV                - battVoltTable[i + 1];
      float frac  = pos / range;
      int   pct   = battPctTable[i + 1] + (int)(frac * (battPctTable[i] - battPctTable[i + 1]));
      return constrain(pct, 0, 100);
    }
  }
  return 0;
}

// ─────────────────────────────────────────────────────────────────────────────
// BACKLIGHT
// ─────────────────────────────────────────────────────────────────────────────
void setBacklight(int val) { ledcWrite(BACKLIGHT, val); }

void wakeScreen() {
  blState      = BL_STATE_BRIGHT;
  lastActivity = millis();
  setBacklight(BL_BRIGHT);
}

void updateBacklight() {
  if (currentScreen == SCR_GAME || showingAlert) return;
  unsigned long elapsed = millis() - lastActivity;
  bool pomRunning     = (slots[SLOT_POMODORO].state == SLOT_RUNNING);
  bool curGoalRunning = (slots[SLOT_CURGOAL].state  == SLOT_RUNNING);
  bool genRunning     = (slots[SLOT_GENERAL].state  == SLOT_RUNNING);
  bool otherRunning   = pomRunning || genRunning;
  bool anyRunning     = pomRunning || curGoalRunning || genRunning || sw.running;

  if (blState == BL_STATE_BRIGHT) {
    if (elapsed > T_DIM) { blState = BL_STATE_DIM; setBacklight(BL_DIM); }
  } else if (blState == BL_STATE_DIM) {
    if (otherRunning || sw.running) return;
    if (curGoalRunning && !otherRunning) {
      if (elapsed > T_OFF_CURGOAL) { blState = BL_STATE_OFF; setBacklight(BL_OFF); }
      return;
    }
    if (!anyRunning) {
      if (elapsed > T_OFF_NOTHING) { blState = BL_STATE_OFF; setBacklight(BL_OFF); }
    }
  }
}

// ─────────────────────────────────────────────────────────────────────────────
// PRINT HELPERS
// ─────────────────────────────────────────────────────────────────────────────
void print2(int v) { if (v < 10) lcd.print('0'); lcd.print(v); }

void printPadded(const char* str, int width) {
  int len = strlen(str);
  lcd.print(str);
  for (int i = len; i < width; i++) lcd.print(' ');
}

void printBattery() {
  int pct = getBattery();
  lcd.setCursor(12, 0);
  char buf[5];
  snprintf(buf, sizeof(buf), "%3d%%", pct);
  lcd.print(buf);
}

void printCompactFull(unsigned long secs) {
  long d = secs / 86400;
  long h = (secs % 86400) / 3600;
  long m = (secs % 3600) / 60;
  long s = secs % 60;
  print2((int)d); lcd.print("d ");
  print2((int)h); lcd.print("h ");
  print2((int)m); lcd.print("m ");
  print2((int)s); lcd.print("s");
}

void printTimerTime(unsigned long secs) {
  long h = secs / 3600;
  long m = (secs % 3600) / 60;
  long s = secs % 60;
  print2((int)h); lcd.print("h ");
  print2((int)m); lcd.print("m ");
  print2((int)s); lcd.print("s  ");
}

// ─────────────────────────────────────────────────────────────────────────────
// NVS
// ─────────────────────────────────────────────────────────────────────────────
void saveSlot(int i) {
  prefs.begin(NVS_NS[i], false);
  prefs.putInt("state",  (int)slots[i].state);
  prefs.putLong("days",  slots[i].setDays);
  prefs.putLong("hrs",   slots[i].setHours);
  prefs.putLong("mins",  slots[i].setMins);
  prefs.putULong("rem",  slots[i].remainingSeconds);
  prefs.end();
}

bool loadAllSlots() {
  bool hadRunning = false;
  for (int i = 0; i < NUM_SLOTS; i++) {
    prefs.begin(NVS_NS[i], true);
    slots[i].state            = (SlotState)prefs.getInt("state", (int)SLOT_IDLE);
    slots[i].setDays          = prefs.getLong("days", 0);
    slots[i].setHours         = prefs.getLong("hrs",  0);
    slots[i].setMins          = prefs.getLong("mins", 0);
    slots[i].remainingSeconds = prefs.getULong("rem", 0);
    slots[i].targetMillis     = 0;
    prefs.end();
    if (slots[i].state == SLOT_RUNNING) {
      if (slots[i].remainingSeconds == 0) {
        slots[i].state = SLOT_FINISHED;
        saveSlot(i);
      } else {
        hadRunning = true;
      }
    }
  }
  return hadRunning;
}

void resumeRunningSlots() {
  for (int i = 0; i < NUM_SLOTS; i++)
    if (slots[i].state == SLOT_RUNNING && slots[i].remainingSeconds > 0)
      slots[i].targetMillis = millis() + slots[i].remainingSeconds * 1000UL;
}

void clearSlot(int i) {
  slots[i] = { SLOT_IDLE, 0, 0, 0, 0, 0 };
  saveSlot(i);
}

// Returns shortest running countdown slot — timer takes priority in idle logic
int shortestRunningSlot() {
  int best = -1;
  unsigned long bestSecs = 0xFFFFFFFF;
  for (int i = 0; i < NUM_SLOTS; i++) {
    if (slots[i].state == SLOT_RUNNING && slots[i].remainingSeconds < bestSecs) {
      bestSecs = slots[i].remainingSeconds;
      best = i;
    }
  }
  return best;
}

bool anyCountdownRunning() {
  for (int i = 0; i < NUM_SLOTS; i++)
    if (slots[i].state == SLOT_RUNNING) return true;
  return false;
}

// ─────────────────────────────────────────────────────────────────────────────
// SNAKE ANIMATION
// ─────────────────────────────────────────────────────────────────────────────
void snakeIndexToPos(int idx, int& col, int& row) {
  idx = ((idx % 30) + 30) % 30;
  if      (idx < 16)  { col = idx;         row = 0; }
  else if (idx == 16) { col = 15;          row = 1; }
  else                { col = 15-(idx-16); row = 1; }
}

int snakeDirection(int pos) {
  int idx = ((pos % 30) + 30) % 30;
  if      (idx < 15)  return 0;
  else if (idx == 15) return 1;
  else if (idx == 16) return 2;
  else                return 2;
}

void loadSnakeHeadChar(int dir) {
  if (lastSnakeDir == dir) return;
  lastSnakeDir = dir;
  byte* h;
  switch (dir) {
    case 0: h = charHeadR; break;
    case 1: h = charHeadD; break;
    case 2: h = charHeadL; break;
    default:h = charHeadU; break;
  }
  lcd.createChar(2, h);
}

void drawSnake() {
  lcd.clear();
  printBattery();
  const int SNAKE_LEN = 8;
  int dir = snakeDirection(snakePos);
  loadSnakeHeadChar(dir);
  for (int i = 0; i < SNAKE_LEN; i++) {
    int col, row;
    snakeIndexToPos(snakePos - i, col, row);
    if (row == 0 && col >= 12) continue;
    lcd.setCursor(col, row);
    if      (i == 0) lcd.write((uint8_t)2);
    else if (i == 1) lcd.write((uint8_t)3);
    else             lcd.write((uint8_t)4);
  }
}

// ─────────────────────────────────────────────────────────────────────────────
// DODGE DUCK GAME
// ─────────────────────────────────────────────────────────────────────────────
int nextObsRow(int lastRow) {
  dg.obsPatternCount++;
  if (dg.sameRowCount >= 3) {
    dg.sameRowCount    = 0;
    dg.obsPatternCount = 0;
    dg.obsPattern      = random(0, 2);
    return 1 - lastRow;
  }
  if (dg.obsPatternCount >= 4) {
    dg.obsPattern      = random(0, 3);
    dg.obsPatternCount = 0;
  }
  int nextRow;
  switch (dg.obsPattern) {
    case 0: nextRow = 1 - lastRow;  break;
    case 1: nextRow = lastRow;      break;
    default:nextRow = random(0, 2); break;
  }
  if (nextRow == lastRow) dg.sameRowCount++;
  else                    dg.sameRowCount = 0;
  return nextRow;
}

void dgInit() {
  lcd.createChar(5, charDuck);
  lcd.createChar(6, charBullet);
  dg.playerRow       = 1;
  dg.obs1Col         = 15;
  dg.obs1Row         = random(0, 2);
  dg.obs2Col         = 8;
  dg.obs2Row         = 1 - dg.obs1Row;
  dg.lastSecondTick  = 0;
  dg.displayScore    = 0;
  dg.dead            = false;
  dg.started         = false;
  dg.paused          = false;
  dg.tickMs          = DODGE_TICK_START;
  dg.lastSpeedUp     = 0;
  dg.obsPattern      = 0;
  dg.obsPatternCount = 0;
  dg.sameRowCount    = 0;
  lastDodgeTick      = millis();
}

void drawDodge() {
  lcd.clear();
  printBattery();
  if (!dg.started) {
    lcd.setCursor(1, 0); lcd.print("DODGE DUCK!");
    lcd.setCursor(1, 1); lcd.print("UP/DN to start");
    return;
  }
  if (dg.paused) {
    lcd.setCursor(0, dg.playerRow); lcd.write((uint8_t)5);
    if (dg.obs1Col >= 1 && dg.obs1Col < 16) { lcd.setCursor(dg.obs1Col, dg.obs1Row); lcd.write((uint8_t)6); }
    if (dg.obs2Col >= 1 && dg.obs2Col < 16) { lcd.setCursor(dg.obs2Col, dg.obs2Row); lcd.write((uint8_t)6); }
    lcd.setCursor(11, 1);
    char buf[6]; snprintf(buf, sizeof(buf), "%3ds", dg.displayScore); lcd.print(buf);
    lcd.setCursor(4, 0); lcd.print("PAUSED");
    return;
  }
  if (dg.dead) {
    lcd.setCursor(2, 0); lcd.print("** DEAD **");
    lcd.setCursor(2, 1); lcd.print("OK=retry ");
    lcd.setCursor(11, 1);
    char buf[6]; snprintf(buf, sizeof(buf), "%3ds", dg.displayScore); lcd.print(buf);
    return;
  }
  lcd.setCursor(0, dg.playerRow); lcd.write((uint8_t)5);
  if (dg.obs1Col >= 1 && dg.obs1Col < 16) { lcd.setCursor(dg.obs1Col, dg.obs1Row); lcd.write((uint8_t)6); }
  if (dg.obs2Col >= 1 && dg.obs2Col < 16) { lcd.setCursor(dg.obs2Col, dg.obs2Row); lcd.write((uint8_t)6); }
  lcd.setCursor(11, 1);
  char buf[6]; snprintf(buf, sizeof(buf), "%3ds", dg.displayScore); lcd.print(buf);
}

void dgTick() {
  if (!dg.started || dg.dead || dg.paused) return;
  unsigned long now = millis();
  if (now - dg.lastSpeedUp >= DODGE_SPEED_INTERVAL) {
    dg.lastSpeedUp = now;
    if (dg.tickMs > DODGE_TICK_MIN) { dg.tickMs -= 20UL; if (dg.tickMs < DODGE_TICK_MIN) dg.tickMs = DODGE_TICK_MIN; }
  }
  if (now - dg.lastSecondTick >= 1000UL) { dg.lastSecondTick = now; dg.displayScore++; }
  dg.obs1Col--; dg.obs2Col--;
  if (dg.obs1Col < 0) { dg.obs1Col = 15; dg.obs1Row = nextObsRow(dg.obs2Row); }
  if (dg.obs2Col < 0) { dg.obs2Col = 15; dg.obs2Row = nextObsRow(dg.obs1Row); }
  if ((dg.obs1Col == 0 && dg.obs1Row == dg.playerRow) ||
      (dg.obs2Col == 0 && dg.obs2Row == dg.playerRow)) {
    dg.dead = true; drawDodge(); return;
  }
  drawDodge(); printBattery();
}

void handleDodge() {
  if (buttonPressed(BTN_BACK)) {
    lcd.createChar(2, charArrow);
    lcd.clear(); currentScreen = SCR_MAIN; redraw(); waitRelease(BTN_BACK); return;
  }
  if (buttonPressed(BTN_UP)) {
    if (!dg.started) {
      dg.started=true; dg.paused=false;
      dg.lastSpeedUp=millis(); dg.lastSecondTick=millis(); lastDodgeTick=millis(); drawDodge();
    } else if (!dg.dead && !dg.paused) { dg.playerRow=0; drawDodge(); }
    waitRelease(BTN_UP);
  }
  if (buttonPressed(BTN_DOWN)) {
    if (!dg.started) {
      dg.started=true; dg.paused=false;
      dg.lastSpeedUp=millis(); dg.lastSecondTick=millis(); lastDodgeTick=millis(); drawDodge();
    } else if (!dg.dead && !dg.paused) { dg.playerRow=1; drawDodge(); }
    waitRelease(BTN_DOWN);
  }
  if (buttonPressed(BTN_SELECT)) {
    if (dg.dead) {
      dgInit(); dg.started=true;
      dg.lastSpeedUp=millis(); dg.lastSecondTick=millis(); lastDodgeTick=millis(); drawDodge();
    } else if (dg.started) {
      dg.paused=!dg.paused;
      if (!dg.paused) { lastDodgeTick=millis(); dg.lastSpeedUp=millis(); dg.lastSecondTick=millis(); }
      drawDodge();
    }
    waitRelease(BTN_SELECT);
  }
}
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
void loop() {
  unsigned long now = millis();

  // ── Alert dismiss after 2s ──
  if (showingAlert && (now-alertShownAt>2000)) {
    showingAlert=false; alertSlot=-1; redraw();
  }

  // ── Idle screen trigger (2 minutes) ──
  bool isIdleScreen = (currentScreen==SCR_IDLE_SNAKE || currentScreen==SCR_IDLE_FULLSCREEN);
  if (!isIdleScreen && !showingAlert &&
      currentScreen != SCR_GAME &&
      currentScreen != SCR_CONFIRM_RESUME &&
      (now-lastActivity > AUTOFS_TIMEOUT)) {
    screenBeforeIdle = currentScreen;
    // Timer takes priority
    if (sw.running || sw.paused) {
      currentScreen = SCR_IDLE_FULLSCREEN;
    } else {
      int ss = shortestRunningSlot();
      currentScreen = (ss >= 0) ? SCR_IDLE_FULLSCREEN : SCR_IDLE_SNAKE;
      if (currentScreen == SCR_IDLE_SNAKE) {
        lastSnakeDir=-1;
        lcd.createChar(3, charSnakeNeck);
        lcd.createChar(4, charSnakeBody);
      }
    }
    lcd.clear(); redraw();
  }

  // ── Snake animation tick ──
  if (currentScreen==SCR_IDLE_SNAKE && (now-lastSnakeTick>SNAKE_TICK)) {
    lastSnakeTick=now; snakePos++; drawSnake();
  }

  // ── Idle fullscreen — update timer display every second ──
  if (currentScreen==SCR_IDLE_FULLSCREEN && !showingAlert) {
    if (!sw.running && !sw.paused && shortestRunningSlot()<0) {
      lastSnakeDir=-1;
      lcd.createChar(3, charSnakeNeck);
      lcd.createChar(4, charSnakeBody);
      currentScreen=SCR_IDLE_SNAKE; lcd.clear(); redraw();
    }
  }

  // ── Timer full screen live update every second ──
  if ((currentScreen==SCR_TIMER_FULLSCREEN || currentScreen==SCR_IDLE_FULLSCREEN) && sw.running) {
    static unsigned long lastTimerDraw = 0;
    if (now - lastTimerDraw >= 1000UL) { lastTimerDraw=now; redraw(); }
  }

  // ── Button detection ──
  bool anyDown=(digitalRead(BTN_UP)==LOW||digitalRead(BTN_DOWN)==LOW||
                digitalRead(BTN_SELECT)==LOW||digitalRead(BTN_BACK)==LOW);
  if (anyDown) {
    lastActivity=now;
    if (blState!=BL_STATE_BRIGHT) { wakeScreen(); delay(DEBOUNCE); }
    else if (showingAlert) { showingAlert=false; alertSlot=-1; redraw(); delay(DEBOUNCE); }
    else {
      switch (currentScreen) {
        case SCR_MAIN:             handleMainMenu();      break;
        case SCR_SLOT_MENU:        handleSlotMenu();      break;
        case SCR_SET_DAYS:
        case SCR_SET_HOURS:
        case SCR_SET_MINS:         handleSetTime();       break;
        case SCR_FULLSCREEN:       handleFullScreen();    break;
        case SCR_CONFIRM_RESUME:   handleResumePrompt();  break;
        case SCR_GAME:             handleDodge();         break;
        case SCR_TIMER_MENU:       handleTimerMenu();     break;
        case SCR_TIMER_FULLSCREEN: handleTimerFullScreen(); break;
        case SCR_IDLE_SNAKE:
        case SCR_IDLE_FULLSCREEN:  handleIdleScreen();    break;
      }
    }
  }

  // ── Game tick ──
  if (currentScreen==SCR_GAME) {
    if (dg.started && !dg.dead && !dg.paused &&
        (millis()-lastDodgeTick >= dg.tickMs)) {
      lastDodgeTick=millis(); dgTick();
    }
  }

  // ── Backlight management ──
  updateBacklight();

  // ── Countdown tick ──
  if (!showingAlert && currentScreen!=SCR_GAME && currentScreen!=SCR_CONFIRM_RESUME)
    tickAllSlots();

  // ── Periodic NVS save ──
  if (now-lastSaveTime>SAVE_INTERVAL) {
    lastSaveTime=now;
    for (int i=0;i<NUM_SLOTS;i++)
      if (slots[i].state==SLOT_RUNNING) saveSlot(i);
  }

  delay(50);
}

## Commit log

2026-05-11 Revise README with comprehensive project details
    Updated project title and added detailed project description, badges, gallery, features, hardware details, wiring diagram, case design, programming instructions, skills learned, major problems and solutions, planned improvements, repository structure, license, and author information.
2026-05-18 Delete case/Countdown Timer V1 Case.3mf
    Uploaded a renewed one without Date Engraving
    [Countdown Timer V1 Case.3mf]
2026-06-16 Revise My Journey documentation for Countdown Timer V1
    Updated the document to reflect the journey and learning experiences related to the Countdown Timer project, including hardware and software development, challenges faced, and insights gained.
2026-06-25 Revise My Journey with Countdown Timer V1
    Expanded the journey of building the Countdown Timer, detailing the learning process in CAD, hardware assembly, and software development. Included reflections on challenges faced and insights gained 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

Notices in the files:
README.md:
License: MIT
